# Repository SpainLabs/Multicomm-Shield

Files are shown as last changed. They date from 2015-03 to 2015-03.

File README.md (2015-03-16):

Multicomm shield
================



Objetivo
________

Esta shield para Arduino se concibió en SpainLabs y está pensada para poder utilizar los módulos de comunicaciones más comunes de una forma sencilla.



Características
_______________

Los módulos serie que pueden acoplarse son el ESP8266 (ESP-01), HC05 y HC06, XBEE y además existen unos pines independientes para utilizar un dispositivo USB2UART por software.

Los módulos SPI que pueden acoplarse son el NRF24L01 y NRF905.

Al tener Arduino un sólo puerto serie, únicamente se puede utilizar un módulo de comunicaciones serie a la vez, en cambio los que usan el puerto spi pueden ser utilizados al mismo tiempo.

Además la shield incorpora dos formas de conexión para ampliar la lista de módulos:
- Aprovechando el zócalo para xbee, que puede ser activada o desactivada por un switch de 8 posiciones.
- Mediante un zócalo diseñado para placas de topos.

Lista de materiales
___________________

- **1 resistencia SMD 1206 de 10K** 0,01€ 
 http://es.aliexpress.com/item/-/1936731050.html
- **1 condensador SMD 1206 de 100nF** 0,01€
 http://es.aliexpress.com/item/Free-Shipping-100PCS-1206-104-100NF-0-1UF-1206-SMD-capacitance/1096160798.html
- **1 condensador SMD 1206 de 10UF** 0,02€
 http://es.aliexpress.com/item/QIAOTIAN-SMD-1206-Chip-Capacitor-10UF-106M-Y5V-10V-100PCS-Lot/1820137718.html
- **1 diodo SMT schottky** 0,02€
 http://es.aliexpress.com/item/Free-Shipping-100PCS-Schottky-Diode-1A-40V-1N5819-SS14-SMD-SMT/627622453.html
- **1 regulador SOT-223 ASM1117** 0,03€
 http://es.aliexpress.com/item/Free-Shipping-100PCS-Original-AMS1117-3-3-AMS1117-3-3V-AMS1117-1117-3-3V-1A-Voltage/1149210196.html
- **2 tiras de pines hembra de 2x4** 0,14€
 http://es.aliexpress.com/item/10x-2-54mm-2x4-Pins-Double-Row-Female-Straight-Header-Pitch-Socket-Pin-Strip-New/32243233137.html
- **1 tira de pines hembra de 2x7** 0,18€
 http://es.aliexpress.com/item/10PCS-2X7-Pin-14P-2-54mm-Double-Row-Female-Straight-Header-Pitch-Socket-Strip/1902481672.html
- **1 tira de pines hembra de 1x4** 0,07€
 http://es.aliexpress.com/item/40pcs-Golden-Single-Row-1x4-pins-2-54mm-Female-Header/877315473.html
- **2 tiras de pines hembra de 1x6** 0,08€
 http://es.aliexpress.com/item/-/2015371109.html
- **2 tiras de pines hembra de 1x10 2mm paso** 0,57€
 http://es.aliexpress.com/item/10-Pcs-Per-Lot-2mm-Pitch-10-Pin-Female-Single-Row-Straight-Pin-Header-Strip/32256838365.html
- **1 tira de pines macho de 1x40** 0,08€
 http://es.aliexpress.com/item/Free-Shipping-10pcs-40-Pin-1x40-Single-Row-Male-2-54-Breakable-Pin-Header-Connector-Strip/2035586129.html
- **1 switch dip de 8 posiciones** 0,19€
 http://www.ebay.co.uk/itm/50-pcs-DMR08T-Dip-Switch-SMD-8-Position-with-Tape-Seal-/261754060756

Librerías externas necesarias
_____________________________

Como la placa ha sido diseñada con el software CADSoft Eagle PCB Design, se han utilizado las siguientes librerías:

- Los diodos schottky de SparkFun-DiscreteSemi https://github.com/sparkfun/SparkFun-Eagle-Libraries
- La shield arduino y xbee de Adafruit https://github.com/adafruit/Adafruit-Eagle-Library

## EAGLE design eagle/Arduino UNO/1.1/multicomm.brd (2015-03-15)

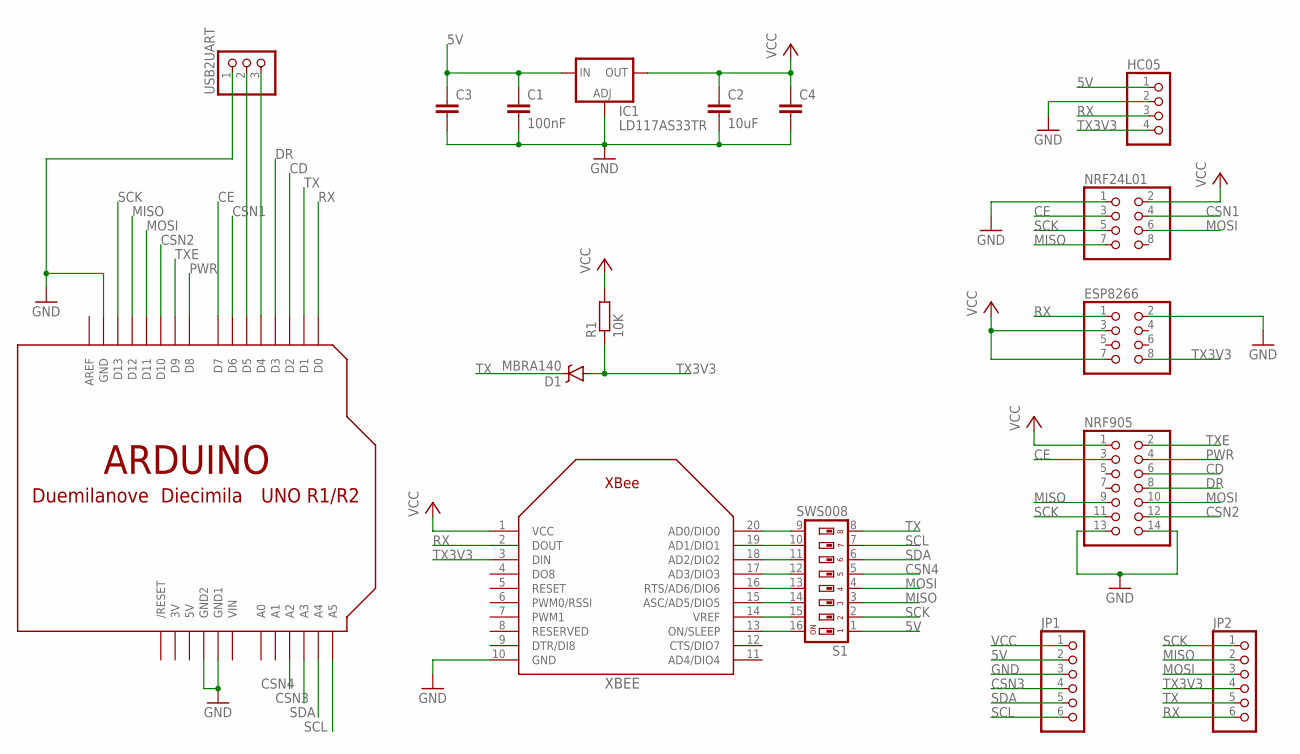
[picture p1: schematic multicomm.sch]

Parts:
C1: 100nF; C1206
C2: 10uF; C1206
C3, C4: C-EUC1206; C1206
D1: MBRA140; SMA-DIODE
ESP8266: PINHD-2X4; 2X04
HC05: PINHD-1X4; 1X04
IC1: LD117AS33TR; SOT223
JP1, JP2: PINHD-1X6; 1X06
NRF24L01: PINHD-2X4; 2X04
NRF905: PINHD-2X7; 2X07
R1: 10K; R1206
S1: SWS008; SMS-008
U$1: ARDUINO-NOHOLE
USB2UART: PINHD-1X3; 1X03
XBEE: XBEE

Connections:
3V: U$1.3V
5V: C1.1, C3.1, HC05.1, IC1.3 (IN), JP1.2, S1.1, U$1.5V
CD: NRF905.6, U$1.D2
CE: NRF24L01.3, NRF905.3, U$1.D7
CSN1: NRF24L01.4, U$1.D6
CSN2: NRF905.12, U$1.D10
CSN3: JP1.4, U$1.A3
CSN4: S1.5, U$1.A2
DR: NRF905.8, U$1.D3
GND: C1.2, C2.2, C3.2, C4.2, ESP8266.2, HC05.2, IC1.1 (ADJ), JP1.3, NRF24L01.1, NRF905.13, NRF905.14, U$1.GND, U$1.GND1, U$1.GND2, USB2UART.1, XBEE.10 (GND)
MISO: JP2.2, NRF24L01.7, NRF905.9, S1.3, U$1.D12
MOSI: JP2.3, NRF24L01.6, NRF905.10, S1.4, U$1.D11
unnamed: U$1.D4, USB2UART.3
unnamed: U$1.D5, USB2UART.2
unnamed: S1.9, XBEE.20 (AD0/DIO0)
unnamed: S1.10, XBEE.19 (AD1/DIO1)
unnamed: S1.11, XBEE.18 (AD2/DIO2)
unnamed: S1.12, XBEE.17 (AD3/DIO3)
unnamed: S1.13, XBEE.16 (RTS/AD6/DIO6)
unnamed: S1.14, XBEE.15 (ASC/AD5/DIO5)
unnamed: S1.15, XBEE.14 (VREF)
unnamed: S1.16, XBEE.13 (ON/SLEEP)
PWR: NRF905.4, U$1.D8
RX: ESP8266.1, HC05.3, JP2.6, U$1.D0, XBEE.2 (DOUT)
SCK: JP2.1, NRF24L01.5, NRF905.11, S1.2, U$1.D13
SCL: JP1.6, S1.7, U$1.A5
SDA: JP1.5, S1.6, U$1.A4
TX: D1.C, JP2.5, S1.8, U$1.D1
TX3V3: D1.A, ESP8266.8, HC05.4, JP2.4, R1.1, XBEE.3 (DIN)
TXE: NRF905.2, U$1.D9
VCC: C2.1, C4.1, ESP8266.3, ESP8266.7, IC1.4 (OUT), JP1.1, NRF24L01.2, NRF905.1, R1.2, XBEE.1 (VCC)
VIN: U$1.VIN

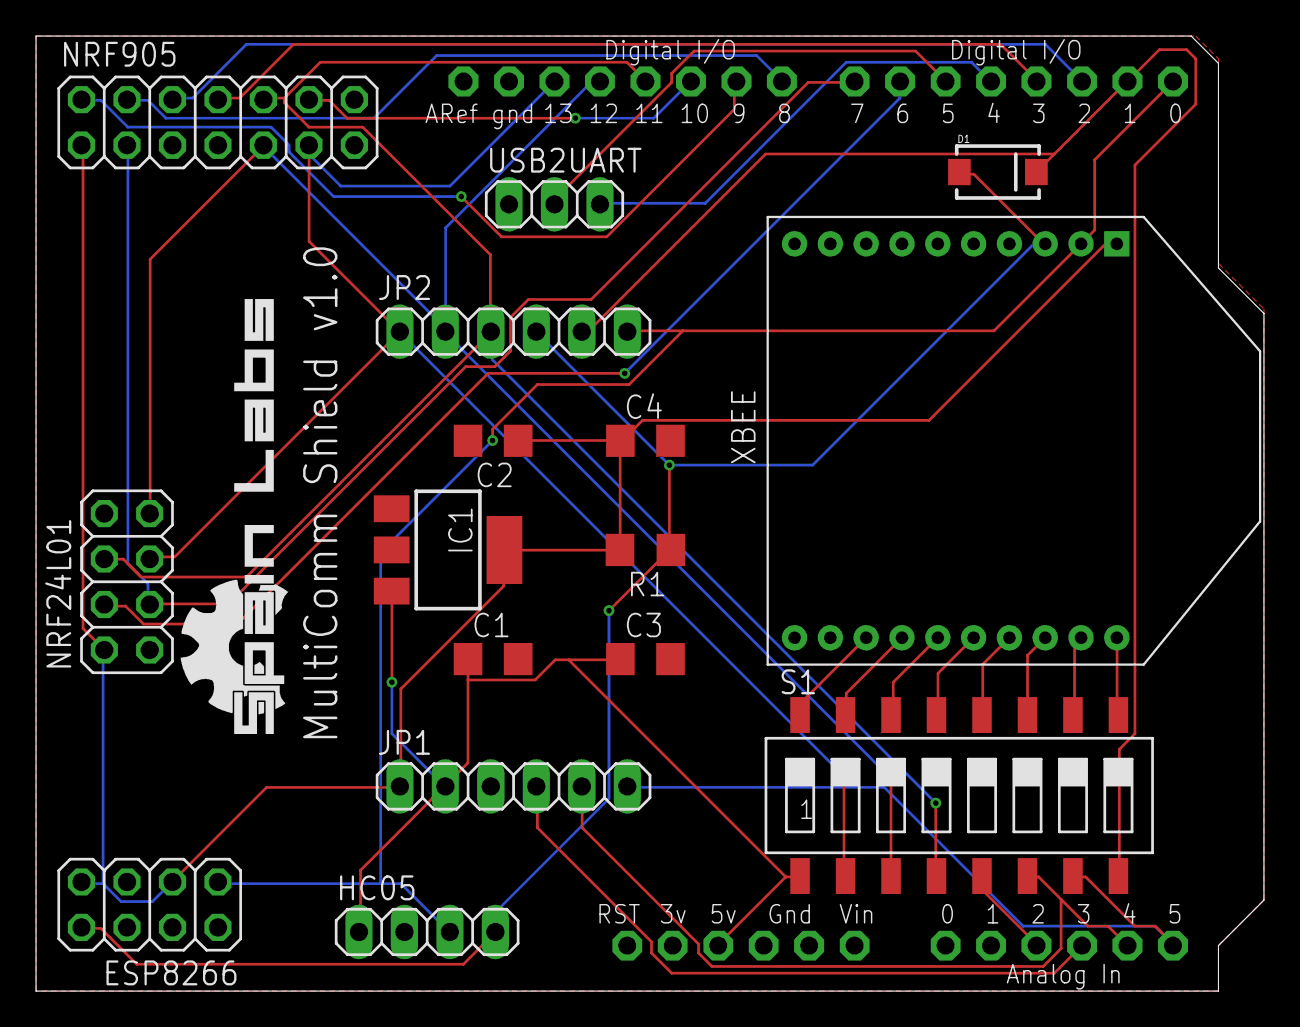
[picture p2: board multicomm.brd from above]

Board: 2 copper layers, 68.6 x 53.3 mm, 18 parts (0 on the bottom side), 30 nets.

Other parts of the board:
U$2: SPAINLABS

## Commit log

2015-03-15 Ficheros de eagle
    Los ficheros del proyecto para el software de diseño de PCBs CadSoft
    Eagle. Este diseño está pensado para placas Arduino Diecimila,
    Duemilanove y UNO.
    [multicomm.brd, multicomm.sch]
2015-03-15 Libreria de logos
    Contiene el logotipo de spainlabs para aplicarlo en la placa.
2015-03-16 Información sobre la placa
    [multicomm.brd, multicomm.sch]

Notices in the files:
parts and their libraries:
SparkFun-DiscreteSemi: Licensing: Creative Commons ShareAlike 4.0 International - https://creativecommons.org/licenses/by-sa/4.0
